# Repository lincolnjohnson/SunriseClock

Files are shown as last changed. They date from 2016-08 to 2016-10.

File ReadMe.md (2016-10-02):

# Arduino SunriseClock v3.2 #
https://github.com/lincolnjohnson/SunriseClock
ReadMe file  
Lincoln Johnson August 2016



---

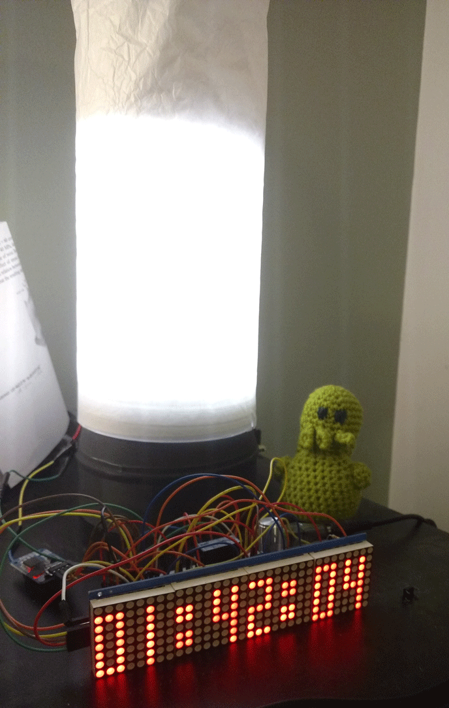
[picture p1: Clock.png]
Crochet Cthulu for scale


## Introduction ##

An LED sunrise clock using an Arduino Pro Micro, 5M 5630 LED strip (300 LEDs/strip), HT1632C 8X32 LED module, DS3231 RTC Module, and rotary encoder with built-in switch.

I've tried a few of the commercially available sunrise clocks, and none of them seem to go bright enough to really help me wake up. So I went with "bigger is better," and maybe a little too far. The LED strip pulls ~72W of power at full brightness, and at 8.5% is sufficient as a standalone light to read or work by.

Should provide ~10,000 lumens at full brightness. Compare that to off-the-shelf sunrise clocks, which generally provide ~300-800 lumens... It's bright enough to hurt my eyes from across the room, and definitely gets me out of bed. I didn't build in functionality to limit the brightness or change the sunrise length, but these would be reasonably trivial to implement if desired.

The clock can be set to natually shift along with the natural sunrise if desired so that you wake up with the real sunrise during the summer months when it shifts earlier.

I've included a schematic and Eagle files for PCB printing. The PCB is designed to be split into two boards, one for the arduino, one for the rotary encoder and switch to be mounted near the top of the case I've designed. Case plans are in the Drawings folder.

Functionality included:

- 16-bit PWM control of LED lamp brightness
- Sunrise brightness uses an exponential function to ramp up brightness in a way that appears linear to the human eye
- User defined Sunrise (alarm) start time, ramps up over 30 minutes
- Choose to have sunrise follow the natural sunrise time or not (with the latest time being the above defined time)
- Automatic dimming after two hours at full brightness
- User-adjustable brightness of light when outside of sunrise period
- Set RTC clock using rotary encoder
- Automatic RTC adjustment for DST
- TODO: ADD WEEKEND AUTOMATIC ADJUSTMENT FOR EXTRA SLEEP TIME

Essentially, once initial program is loaded onto clock it never needs to be re-connected unless you want to update the baseline functionality. You can do everything you should need to do through the various menus.

I made some minor adjustments to a couple of the included libraries or used non-standard versions, so they're included in this repository as well so as to make your life easier if you want to compile/build this. Everything in the includes folder is not my own original work. The other included files listed such as EEPROM and Wire are standard arduino versions.

There are dual signal wires to the MOSFET controlling the LEDs because it seemed that one signal wire wasn't allowing the system to open fully when using a transistor. Not sure why, but doubling up appears to have fixed it - at full duty cycle it's just as bright as a direct connection to power, especially with the first MOSFET switching the source voltage to drive the second one. Now that I've switched to using a MOSFET, one is fine but two signals doesn't hurt so I left it. If you need the extra pin for something else you can always remove one of 9/10 and update the code appropriately.

The Pro Micro tends to be cranky with the Arduino IDE sometimes, especially if you are trying to load code to it for the first time, or switching between sketches. I find that jumpering the RST and GND pins, pressing upload on the IDE, and then disconnecting the jumper as soon as the IDE finishes compiling and outputs the size of the files used fixes this problem. Subsequent uploads with the same sketch should work fine. Not sure if this is a problem related to my use of cheap ebay clones.

I strongly suggest you use a high-quality power supply, as when cheap ebay ones start to die they tend to send out significant voltage spikes that fry things... such as your Arduino.

"Arduino SunriseClock v3.2" by Lincoln Johnson is licensed under CC BY-SA 4.0.
Included libraries are licensed under the licenses provided by their respective creators.

## Usage notes ##

- Run InitialSetup.ino on your Arduino board to initialize EEPROM values and set the time on your RTC [alternatively, these can all be set through the configuration menu]
- Update latitude and longitude values for your location in SunriseClock.ino
- Run SunriseClock.ino on your Arduino board

Pushbutton used to:

- Cancel sunrise if you wake up before it completes
- Toggle clock and light on or off when outside sunrise period and not in configuration menu
- Go back one level in configuration menu, or exit config if on top level

Rotary encoder used to:

- Cycle between configuration menu options or option settings
- Pushbutton used to enter config menu or select menu option displayed

## Electronics BOM ##

- 1x Arduino Pro Micro (Nano also tested and works for base functionality, changes would need to be made to schematic)
- 1x 80W+ power supply (PMT-12V100W1AA)
- 1x 5m 5630 LED strip
- 1x RTC Clock (ebay DS3231 clock module board)
- 1x 8x32 LED display board with HT1632C controller
- 1x 12v->5V DC converter (BP5293-50)
- 1x Pushbutton switch (1825910-6)
- 1x Rotary encoder with pushbutton switch (EN12-HS22AF20)
- 2x 0.1uF capacitor (K104K10X7RF5UH5)
- 2x n-channel mosfet (FQU13N06L)
- 2x 100ohm resistors
- 2x 100kohm resistors
- 2x 12 pin female headers to enable easy replacement of arduino in case of failure (PPTC121LFBN-RC)
- 3x 6 pin headers to connect 3208 matrix and switches board (1x 801-87-006-20-001101 right angle for 3208 & 2x 310-87-106-41-001101 for switches)
- 1x 5 pin header to connect RTC (310-87-105-41-001101)
- 1x 2 pin header to connect LED strip (310-87-102-41-001101)
- 1x screw terminal header for power connection to power supply (1935161)
- Various hookup/connection wires
- Breadboard if no PCB

## Materials used for physical build ##

- 1x 5" to 4" ducting reducer, spray painted matte black
- 1x 4" ducting connector
- 1x 4" ducting cap
- 1x 5" DIA 9" height acrylic canister with white tissue paper as shade
- 1x AC power entry connector (701W-X2/02 or similar)
- 1x Aluminum knob for rotary encoder (Ebay)
- 1x Pushbutton cap for switch (TAGCHR)
- 4.5 ft of 6" wide hardwood for case

## Main Board Schematic ##

This is the main board without the rotary encoder and button on it. If you want it on one board, remove the TOSWITCHES headers and connect them as required.

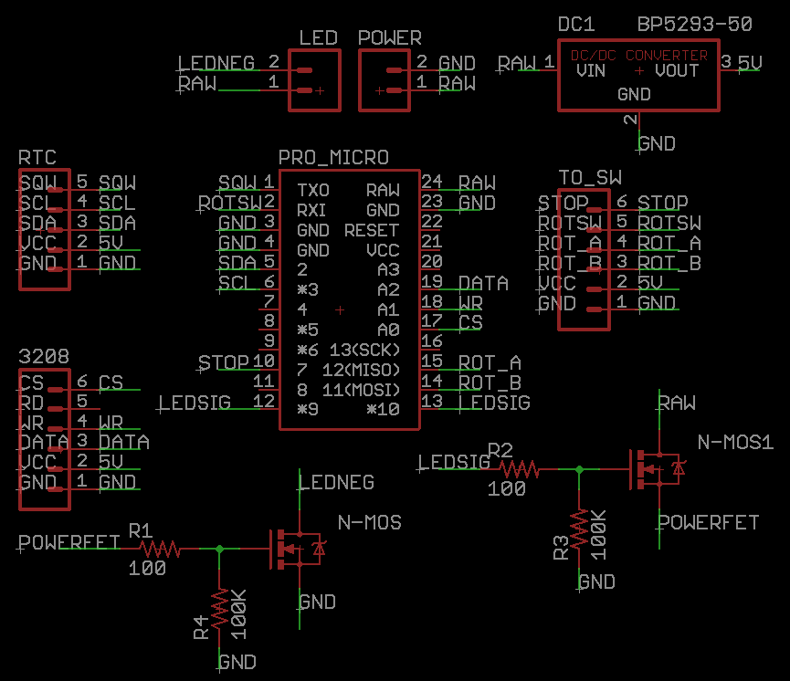
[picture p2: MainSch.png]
Main board schematic


## Eagle Main Board PCB ##

I haven't tested this board yet as it hasn't shown up from the fab. It's probably wrong/may cause a black hole to form and destroy the planet. Use at your own risk. Board size: 1.5464 sqin.

This will need additional physical wires soldered on the LED power ciruit to handle the ~72W power drain if you use the set trace length.

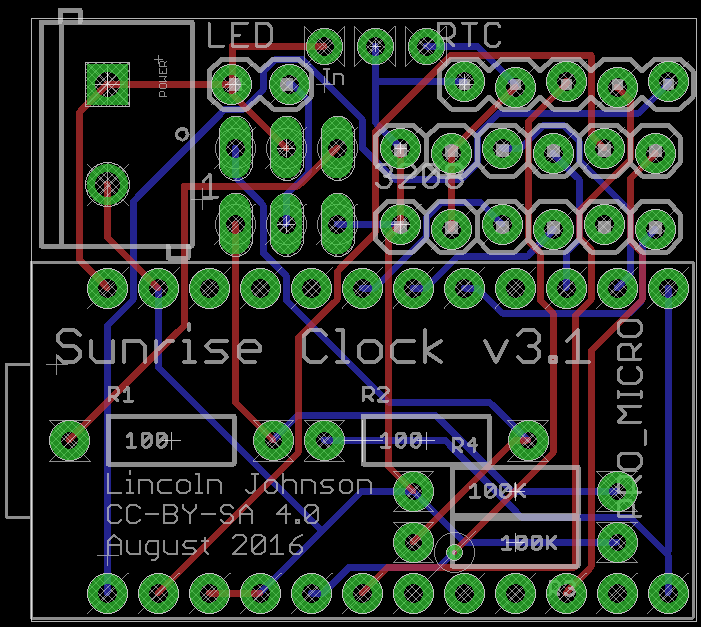
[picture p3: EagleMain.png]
Main eagle PCB


## Switches Board Schematic ##

This is the board with the rotary encoder and button on it. If you want it on one board, remove the TOSWITCHES headers and connect them as required.

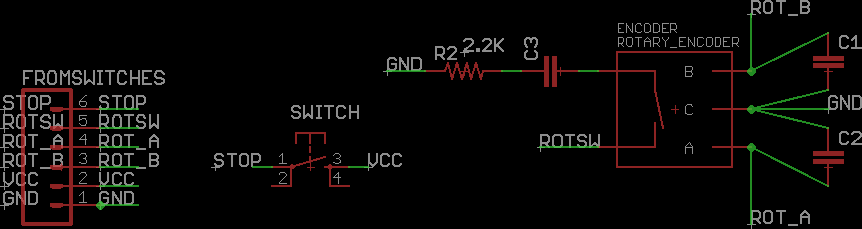
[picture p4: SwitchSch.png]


## Eagle Switches Board PCB ##

I haven't tested this board yet as it hasn't shown up from the fab. It's probably wrong/may cause a black hole to form and destroy the planet. Use at your own risk. Board size: 1.1135 sqin.

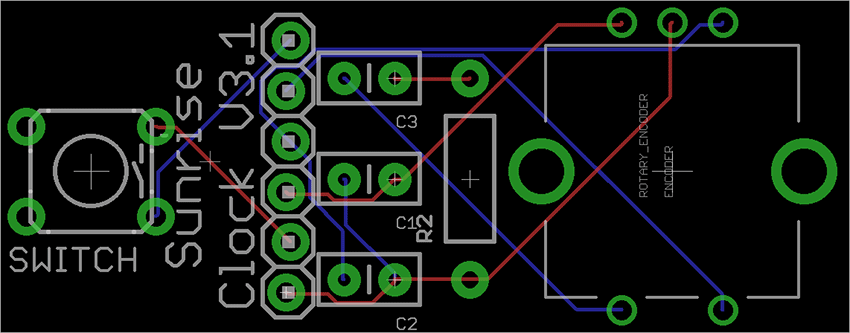
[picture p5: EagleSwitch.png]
Main eagle PCB


## Case Design ##

Complete drawings follow below. Sides not shown as they are solid. PDF with full instructions for construction in Drawings folder.

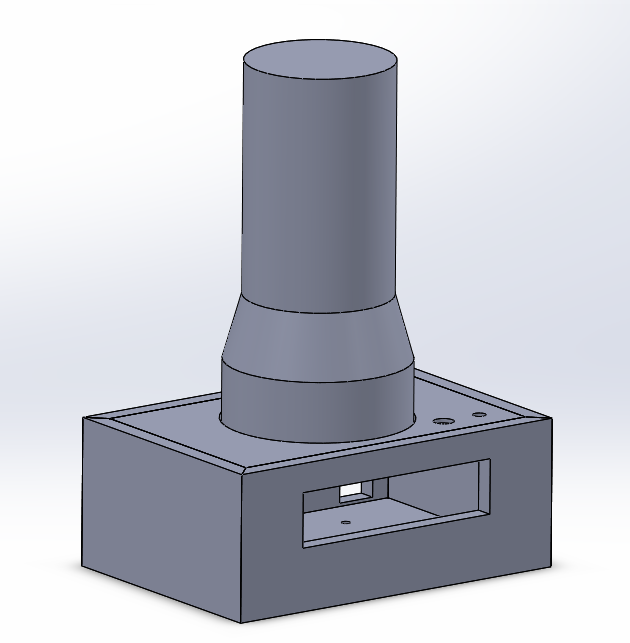
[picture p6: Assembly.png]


###Completed case

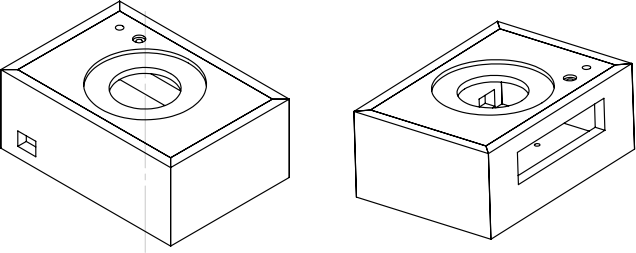
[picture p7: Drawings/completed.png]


###Base drawings

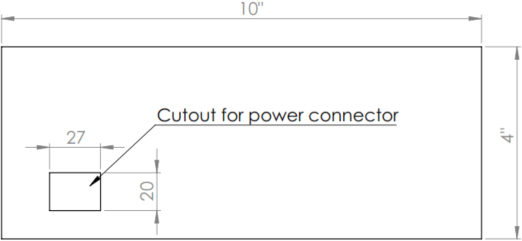
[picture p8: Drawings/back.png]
Base drawings


###Front drawings

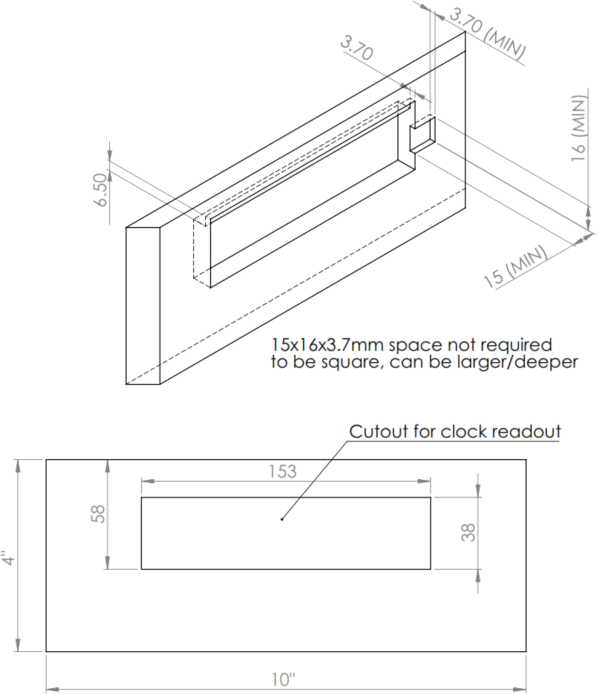
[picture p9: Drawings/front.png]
Front drawings


###Top drawings

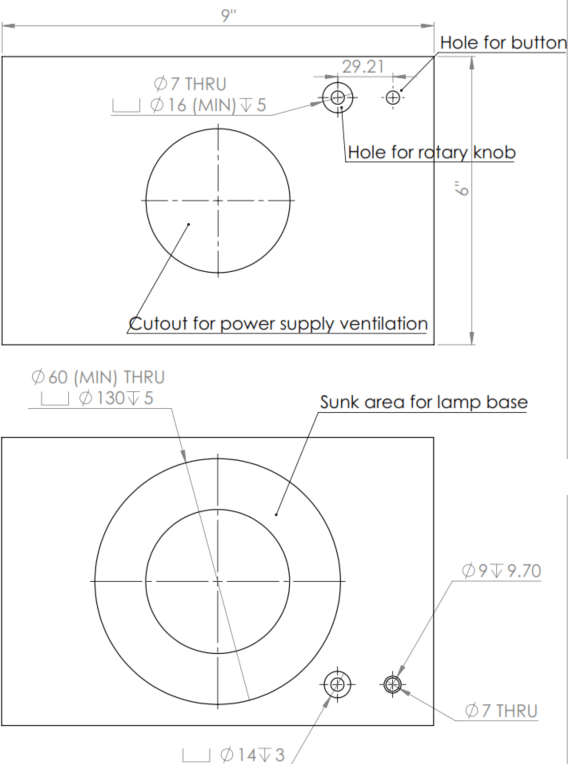
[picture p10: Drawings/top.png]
Top drawings


###Back drawings

Back drawings

## SunriseClock Functions ##

###ISR(PCINT0_vect)
#####Description
Reads the inputs from the rotary encoder gray code to determine if an increment or decrement is desired

###void stop()
#####Description
Called by interrupt, reads the inputs from pushbutton with software debouncing
#####Syntax
`stop();`
#####Parameters
None.
#####Returns
Nothing.

###void toggleLamp(boolean on)
#####Description
Toggles lamp on or off
#####Syntax
`toggleLamp(0);`
#####Parameters
*(boolean)* on - 0 or false is off, 1 or true is on
#####Returns
Nothing.

###void timeUpdate()
#####Description
Called by interrupt generated by 1HZ square wave from RTC - calls showClock() if lamp is on
#####Syntax
`timeUpdate();`
#####Parameters
None.
#####Returns
Nothing.

###void ShowClock()
#####Description
Updates clock display based on current time
#####Syntax
`ShowClock();`
#####Parameters
None.
#####Returns
Nothing.

###bool IsDST()
#####Description
Checks if current time is in DST or not
#####Syntax
`IsDST();`
#####Parameters
None.
#####Returns
0 if currently not in DST, 1 if in DST

###void CheckDST()
#####Description
Checks if currently in DST, updates relevant EEPROM values if there has been a change, updates time on RTC
#####Syntax
`CheckDST();`
#####Parameters
None.
#####Returns
Nothing.

###void setBrightness(unsigned int set)
#####Description
Updates clock brightness
#####Syntax
`setBrightness(60000);`
#####Parameters
*(unsigned int)* set - 65536 is off, 0 is full brightness
#####Returns
Nothing.

###unsigned int readBright()
#####Description
Reads current brightness setting
#####Syntax
`readBright();`
#####Parameters
None.
#####Returns
Current brightness level *(unsigned int)*

###void getSunrise()
#####Description
Calculates sunrise time for next day, updates RTC alarm as necessary
#####Syntax
`getSunrise();`
#####Parameters
None.
#####Returns
Nothing.

###void toggleBlink(boolean blinky)
#####Description
Toggles 250ms blink cycle on LED screen
#####Syntax
`toggleBlink(true);`
#####Parameters
*(boolean)* blinky
#####Returns
Nothing.

###void ClockMenu(String text)
#####Description
Updates LED screen (for when in configuration menu)
#####Syntax
`ClockMenu("Set Clk");`
#####Parameters
*(String)* text
#####Returns
Nothing.

###void knobPress()
#####Description
Controls functionality of rotary encoder switch. Enters menu if currently in clock mode, otherwise selects current menu item shown on LED. Includes software debounce.
#####Syntax
`knobPress();`
#####Parameters
None.
#####Returns
Nothing.

###void KnobSelect()
#####Description
Updates LCD screen for menu navigation
#####Syntax
`KnobSelect();`
#####Parameters
None.
#####Returns
Nothing.

###void KnobUpdate()
#####Description
Called by encoder ISR. Controls update of all config variables, EEPROM updates as necessary.
#####Syntax
`KnobUpdate();`
#####Parameters
None.
#####Returns
Nothing

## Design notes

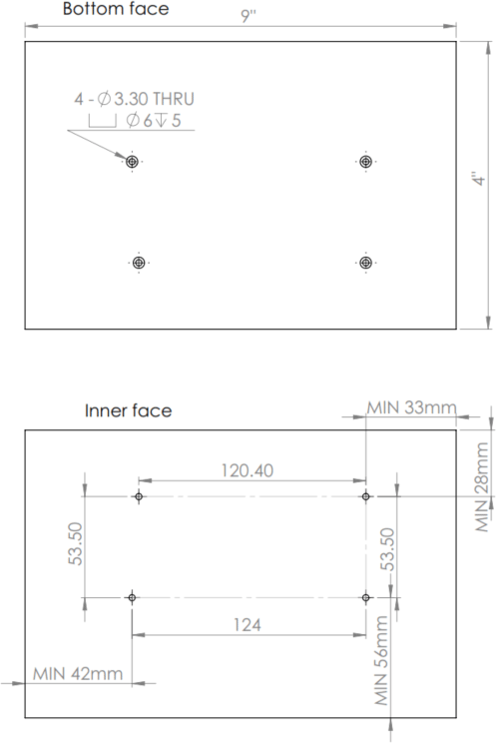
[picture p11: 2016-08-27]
Drawings/base.png

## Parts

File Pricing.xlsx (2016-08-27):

DIGIKEY | Unit cost | Number | Total
TAGCHR | $0.74 | 1 | $0.74
701W-X2/02 | $1.11 | 1 | $1.11
1935161 | $0.53 | 1 | $0.53
310-87-102-41-001101 | $0.30 | 1 | $0.30
310-87-105-41-001101 | $0.51 | 1 | $0.51
801-87-006-20-001101 | $1.12 | 1 | $1.12
310-87-106-41-001101 | $0.63 | 2 | $1.26
FQU13N06L | $1.02 | 1 | $1.02
K104K10X7RF5UH5 | $0.26 | 2 | $0.52
EN12-HS22AF20 | $1.56 | 1 | $1.56
1825910-6 | $0.10 | 1 | $0.10
PMT-12V100W1AA | $32.00 | 1 | $32.00
OSH Park
PCB | $5.76 | 3 | $17.29
Ebay
LED Module (http://www.ebay.com/itm/5M-3528-5050-5630-7020-SMD-LED-Flexible-Waterproof-Strip-String-Light-12V-/351547096821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) | $7.28 | 1 | $7.28
RTC (http://www.ebay.com/itm/Arduino-DS3231-AT24C32-IIC-Module-Precision-RTC-Real-Time-Clock-Quare-Memory-/262123918224) | $0.99 | 1 | $0.99
Pro Micro (http://www.ebay.com/itm/1PCS-Leonardo-Pro-Micro-ATmega32U4-Arduino-IDE-1-0-3-Bootloader-replace-Pro-Mini-/221988214316) | $5.37 | 1 | $5.37
LED matrix (http://www.ebay.com/itm/New-Lattice-Breakout-LED-Module-8X32-Red-Dot-Matrix-Screen-HT1632C-/321866908598) | $14.12 | 1 | $14.12

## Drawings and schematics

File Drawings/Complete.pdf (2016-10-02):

E

F

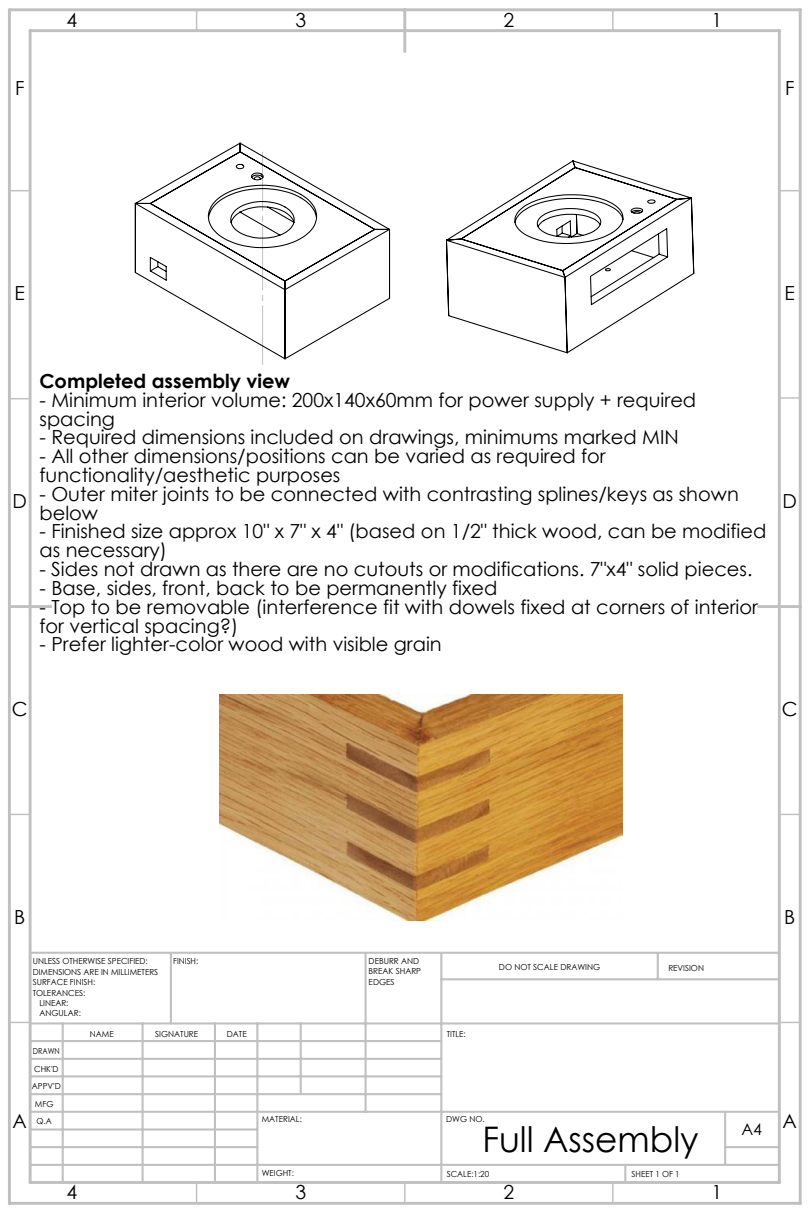
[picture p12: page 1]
FINISH:; DEBURR AND; BREAK SHARP EDGES; DO NOT SCALE DRAWING; REVISION; SCALE:1:20; SHEET 1 OF 1; WEIGHT:

Completed assembly view
- Minimum interior volume: 200x140x60mm for power supply + required
spacing
- Required dimensions included on drawings, minimums marked MIN
- All other dimensions/positions can be varied as required for
functionality/aesthetic purposes
- Outer miter joints to be connected with contrasting splines/keys as shown
below
- Finished size approx 10" x 7" x 4" (based on 1/2" thick wood, can be modified
as necessary)
- Sides not drawn as there are no cutouts or modifications. 7"x4" solid pieces.
- Base, sides, front, back to be permanently fixed
- Top to be removable (interference fit with dowels fixed at corners of interior
for vertical spacing?)
- Prefer lighter-color wood with visible grain

UNLESS OTHERWISE SPECIFIED:
DIMENSIONS ARE IN MILLIMETERS
SURFACE FINISH:
TOLERANCES:
LINEAR:
ANGULAR:

NAME | SIGNATURE | DATE | | | | TITLE:

DRAWN
CHK'D
APPV'D
MFG
Q.A | | | | MATERIAL: | DWG NO. Full Assembly | A4

# 4 - 3.30 THRU

6 5

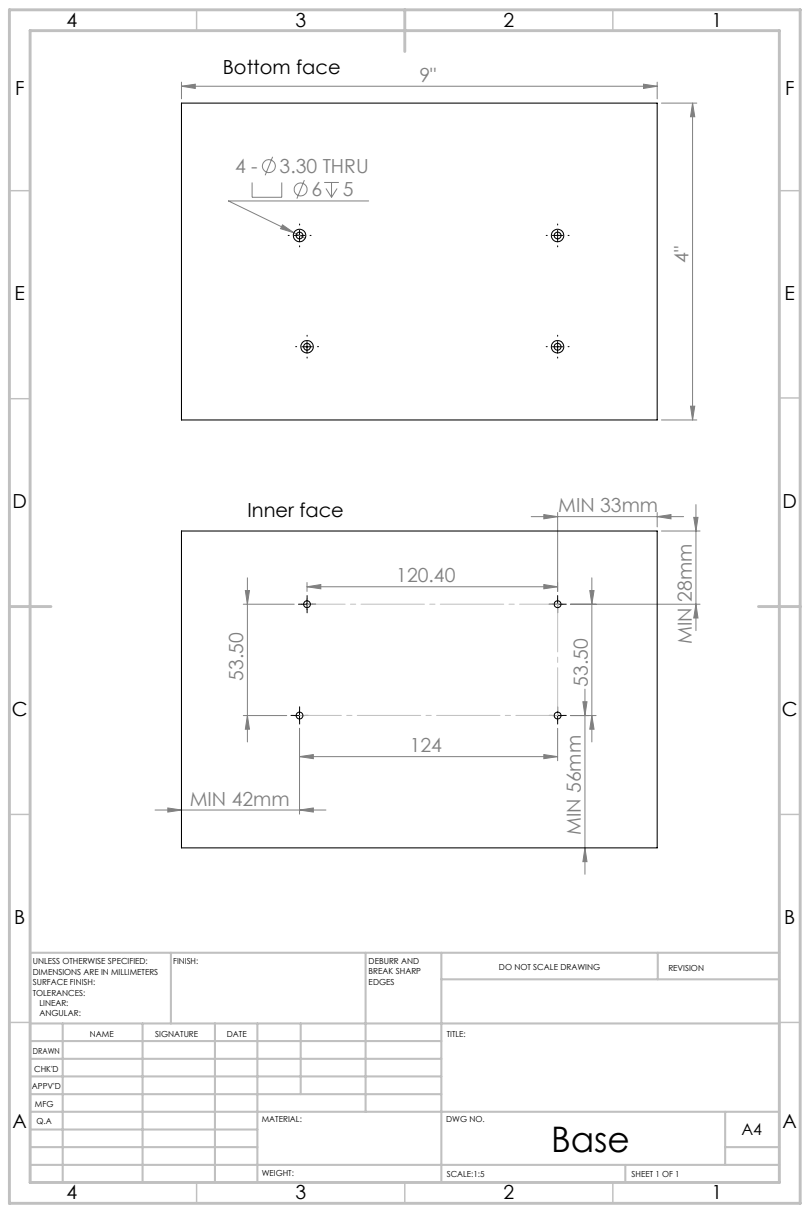
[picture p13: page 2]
Bottom face 53.50; MIN 56mm; MIN 28mm; MIN 33mm; MIN 42mm; Inner face; FINISH:; DEBURR AND; BREAK SHARP EDGES; DO NOT SCALE DRAWING; REVISION

UNLESS OTHERWISE SPECIFIED:
DIMENSIONS ARE IN MILLIMETERS
SURFACE FINISH:
TOLERANCES:
LINEAR:
ANGULAR:

NAME | SIGNATURE | DATE | | | TITLE:

DRAWN
CHK'D
APPV'D
MFG

Base

SCALE:1:5 | SHEET 1 OF 1

# 7 THRU 16 (MIN) 5

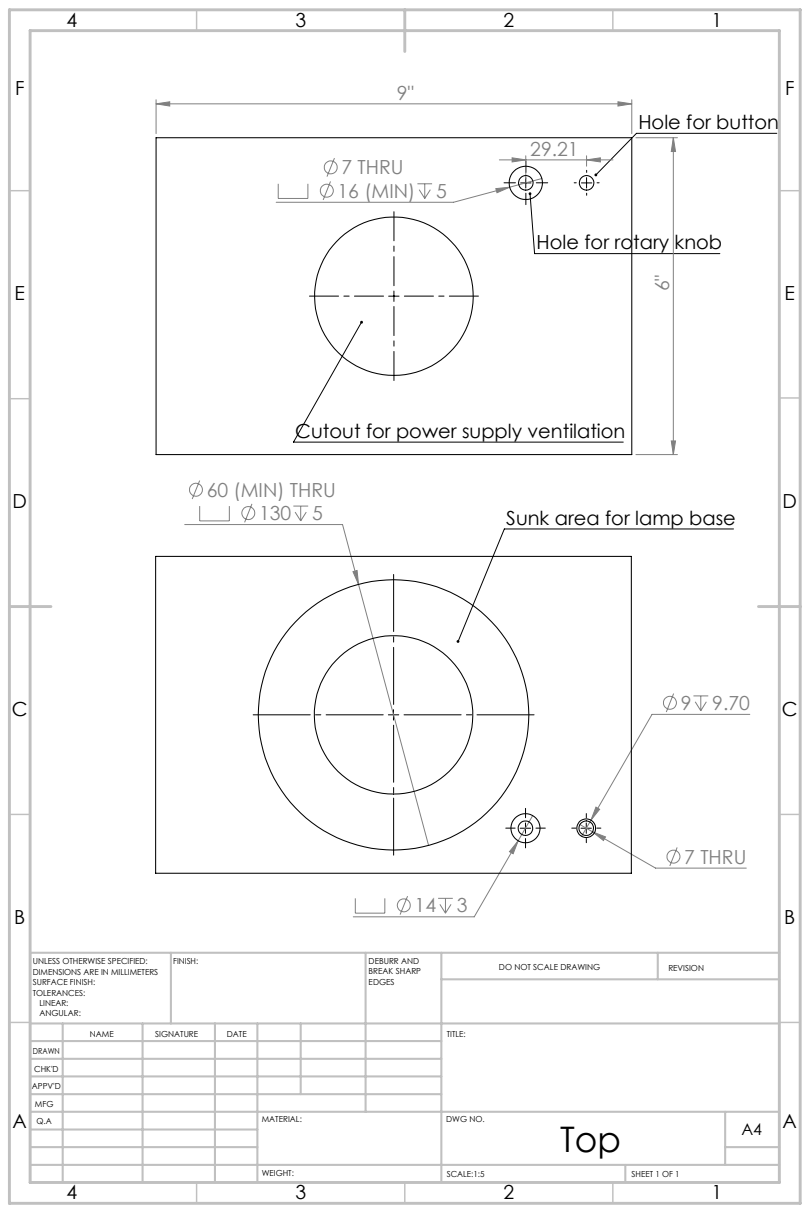
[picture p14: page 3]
60 (MIN) THRU 130 5; 7 THRU; FINISH:; DEBURR AND; BREAK SHARP EDGES; DO NOT SCALE DRAWING; REVISION

Hole for button

Hole for rotary knob

Cutout for power supply ventilation

Sunk area for lamp base

UNLESS OTHERWISE SPECIFIED:
DIMENSIONS ARE IN MILLIMETERS
SURFACE FINISH:
TOLERANCES:
LINEAR:
ANGULAR:

NAME | SIGNATURE | DATE | | TITLE:

DRAWN
CHK'D
APPV'D
MFG

Top

E

F

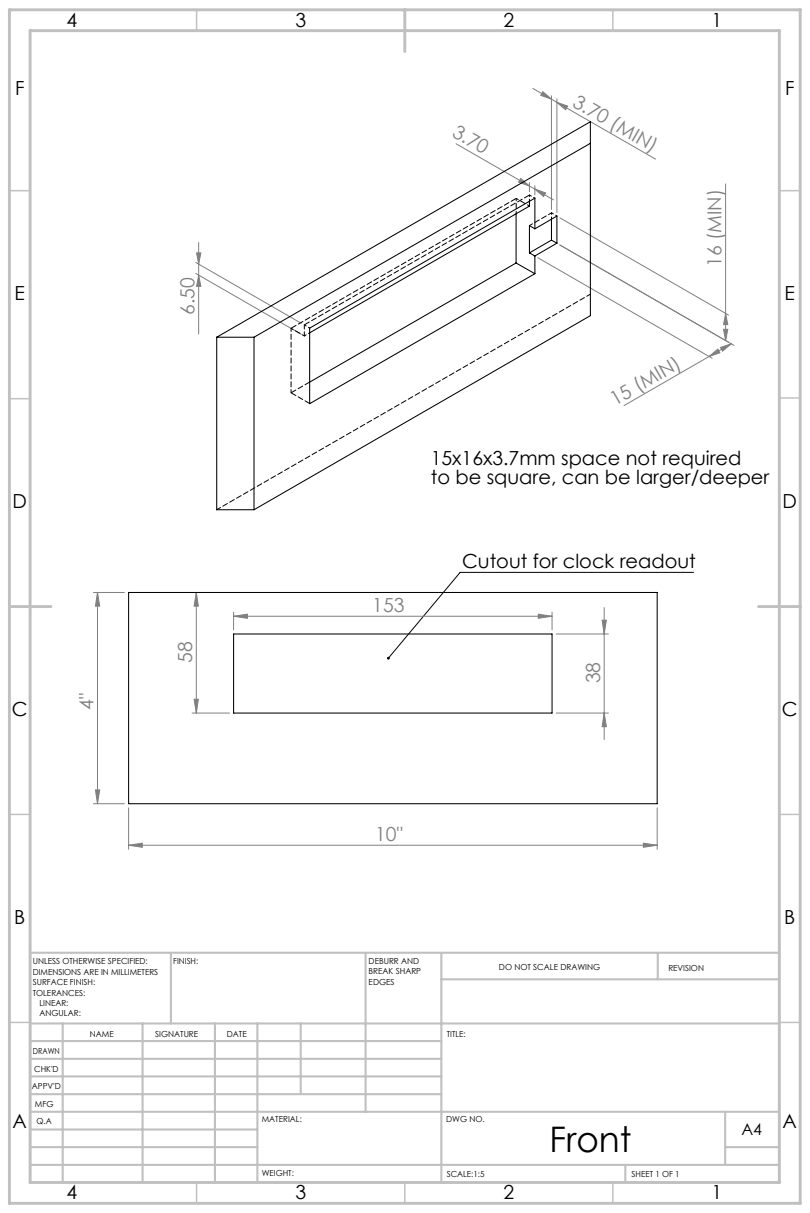
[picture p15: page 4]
3.70 (MIN); 15 (MIN); 16 (MIN); FINISH:; DEBURR AND; BREAK SHARP EDGES; DO NOT SCALE DRAWING; REVISION

15x16x3.7mm space not required
to be square, can be larger/deeper

Cutout for clock readout

UNLESS OTHERWISE SPECIFIED:
DIMENSIONS ARE IN MILLIMETERS
SURFACE FINISH:
TOLERANCES:
LINEAR:
ANGULAR:

NAME | SIGNATURE | DATE | | TITLE:

DRAWN
CHK'D
APPV'D
MFG

Front

10"

E

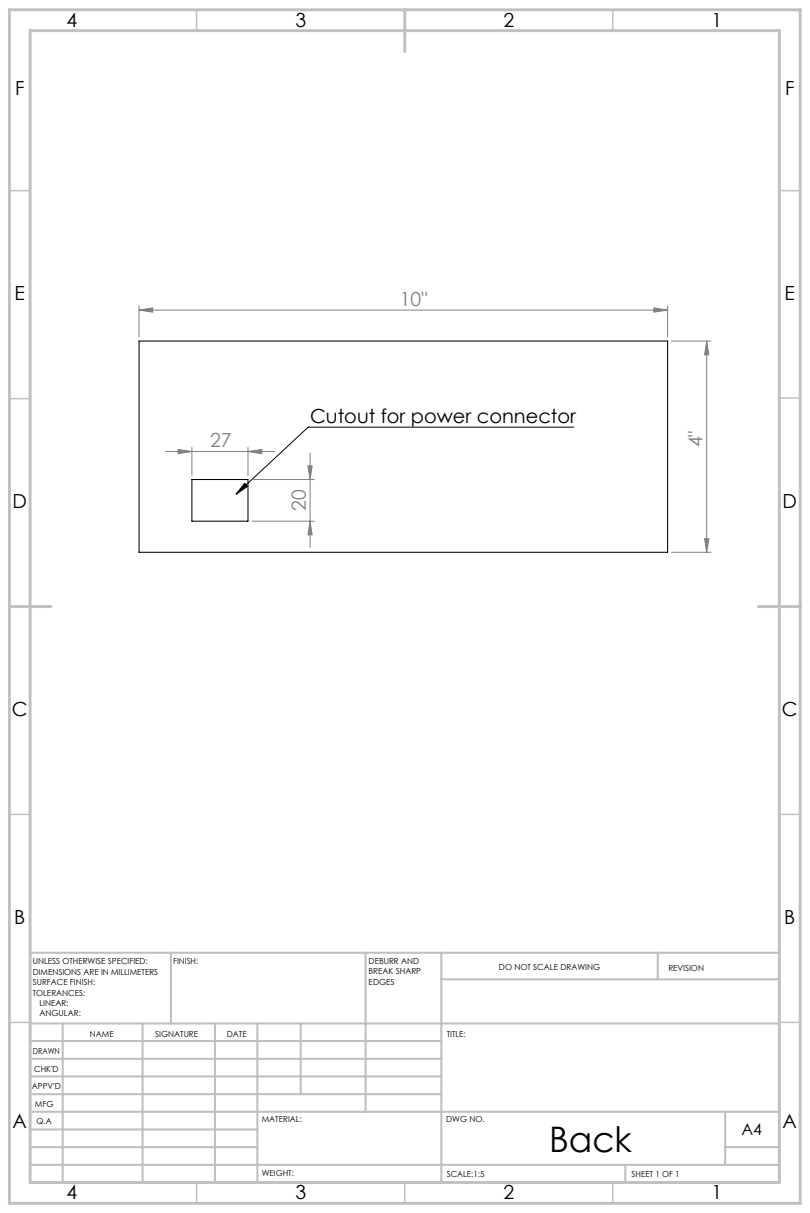
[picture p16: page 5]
FINISH:; DEBURR AND; BREAK SHARP EDGES; DO NOT SCALE DRAWING; REVISION

Cutout for power connector

UNLESS OTHERWISE SPECIFIED:
DIMENSIONS ARE IN MILLIMETERS
SURFACE FINISH:
TOLERANCES:
LINEAR:
ANGULAR:

NAME | SIGNATURE | DATE | | TITLE:

DRAWN
CHK'D
APPV'D
MFG

Back

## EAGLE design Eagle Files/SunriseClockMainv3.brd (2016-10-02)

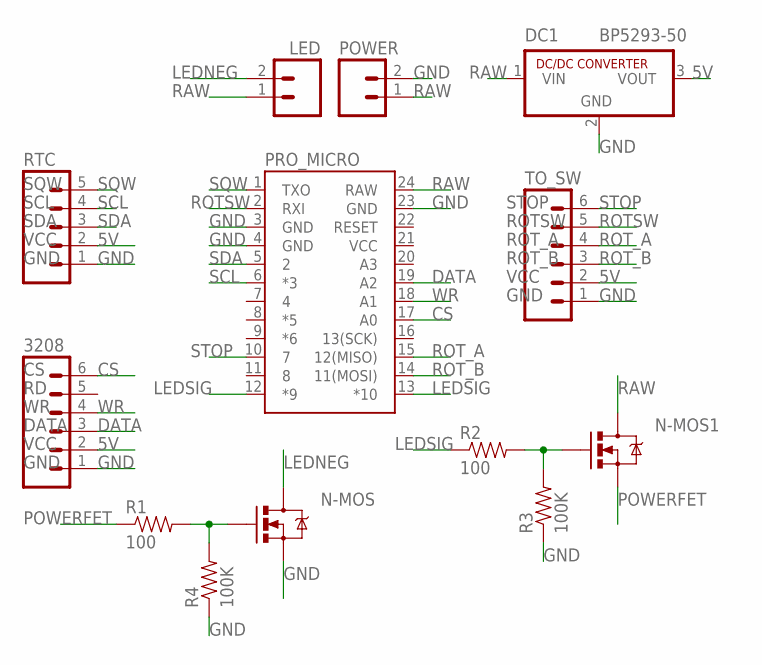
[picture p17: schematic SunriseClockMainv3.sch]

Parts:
3208: M06LOCK; 1X06_LOCK
DC1: BP5293-50; SIP3
LED: M02LOCK; 1X02_LOCK
N-MOS, N-MOS1: MOSFET-NCHANNELFQP30N06L; TO220V
POWER: M025MM; SCREWTERMINAL-5MM-2
PRO_MICRO: ARDUINO_PRO_MICRO
R1, R2: 100; AXIAL-0.4
R3, R4: 100K; AXIAL-0.4
RTC: M05LOCK; 1X05_LOCK
TO_SW: M06LOCK; 1X06_LOCK

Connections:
5V: 3208.2, DC1.3 (VOUT), RTC.2, TO_SW.2
CS: 3208.6, PRO_MICRO.17 (A0)
DATA: 3208.3, PRO_MICRO.19 (A2)
GND: 3208.1, DC1.2 (GND), N-MOS.3 (S), POWER.2, PRO_MICRO.3 (GND), PRO_MICRO.4 (GND), PRO_MICRO.23 (GND), R3.P$1 (1), R4.P$1 (1), RTC.1, TO_SW.1
LEDNEG: LED.2, N-MOS.2 (D)
LEDSIG: PRO_MICRO.12 (*9), PRO_MICRO.13 (*10), R2.P$1 (1)
unnamed: N-MOS.1 (G), R1.P$2 (2), R4.P$2 (2)
unnamed: N-MOS1.1 (G), R2.P$2 (2), R3.P$2 (2)
POWERFET: N-MOS1.3 (S), R1.P$1 (1)
RAW: DC1.1 (VIN), LED.1, N-MOS1.2 (D), POWER.1, PRO_MICRO.24 (RAW)
ROTSW: PRO_MICRO.2 (RXI), TO_SW.5
ROT_A: PRO_MICRO.15 (12(MISO)), TO_SW.4
ROT_B: PRO_MICRO.14 (11(MOSI)), TO_SW.3
SCL: PRO_MICRO.6 (*3), RTC.4
SDA: PRO_MICRO.5 (2), RTC.3
SQW: PRO_MICRO.1 (TXO), RTC.5
STOP: PRO_MICRO.10 (7), TO_SW.6
WR: 3208.4, PRO_MICRO.18 (A1)

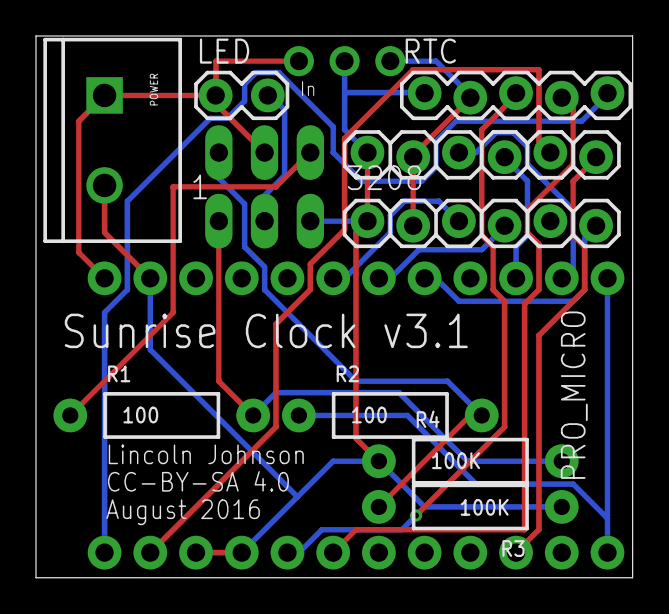
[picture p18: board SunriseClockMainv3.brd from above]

Board: 2 copper layers, 33.1 x 30.1 mm, 13 parts (0 on the bottom side), 18 nets.

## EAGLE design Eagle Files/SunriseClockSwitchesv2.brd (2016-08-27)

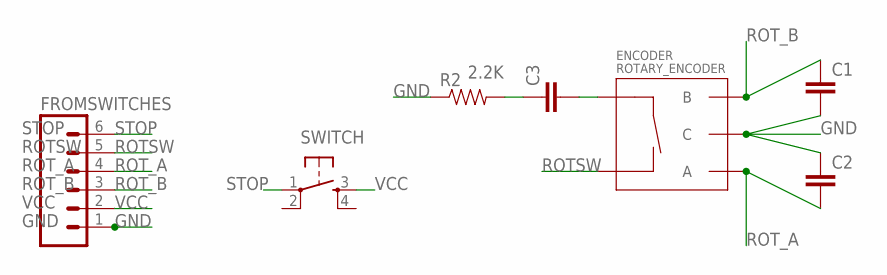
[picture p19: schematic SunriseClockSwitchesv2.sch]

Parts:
C1, C2, C3: CAPEZ; CAP-PTH-SMALLEZ
ENCODER: ROTARY_ENCODER; ROTARY_ENC_PLAIN
FROMSWITCHES: M06LOCK; 1X06_LOCK
R2: RESISTORPTH-1/4W; AXIAL-0.4
SWITCH: TAC_SWITCHPTH; TACTILE-PTH

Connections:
GND: C1.2, C2.1, ENCODER.C, FROMSWITCHES.1, R2.P$1 (1)
unnamed: C3.1, R2.P$2 (2)
unnamed: C3.2, ENCODER.SW+
ROTSW: ENCODER.SW-, FROMSWITCHES.5
ROT_A: C2.2, ENCODER.A, FROMSWITCHES.4
ROT_B: C1.1, ENCODER.B, FROMSWITCHES.3
STOP: FROMSWITCHES.6, SWITCH.1
VCC: FROMSWITCHES.2, SWITCH.3

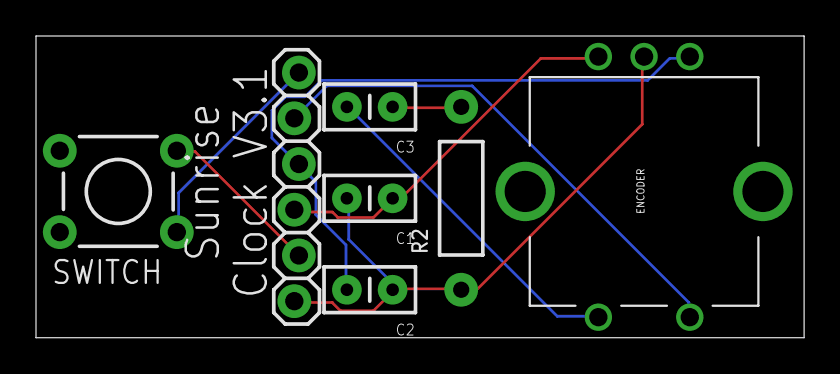
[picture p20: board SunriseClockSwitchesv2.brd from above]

Board: 2 copper layers, 42.7 x 16.8 mm, 7 parts (0 on the bottom side), 8 nets.

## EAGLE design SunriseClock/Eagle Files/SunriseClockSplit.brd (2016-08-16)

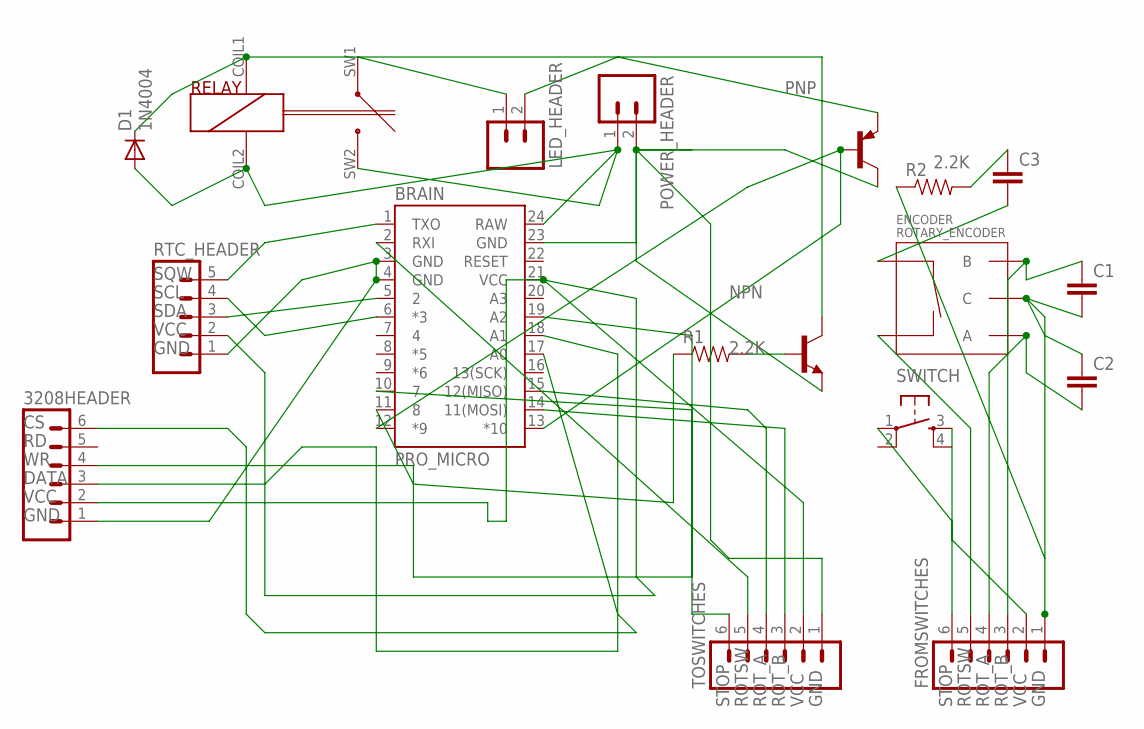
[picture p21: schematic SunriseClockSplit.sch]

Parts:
3208HEADER: M06LOCK; 1X06_LOCK
BRAIN: PRO_MICRO; ARDUINO_PRO_MICRO
C1, C2, C3: CAPEZ; CAP-PTH-SMALLEZ
D1: 1N4004; DO41-10
ENCODER: ROTARY_ENCODER; ROTARY_ENC_PLAIN
FROMSWITCHES: M06LOCK; 1X06_LOCK
LED_HEADER: M02LOCK; 1X02_LOCK
NPN: -NPN-TO126V; TO126V
PNP: -PNP-TO126V; TO126V
POWER_HEADER: M025MM; SCREWTERMINAL-5MM-2
R1, R2: RESISTORPTH-1/4W; AXIAL-0.4
RELAY: RELAY; HALLER_RELAIS_2PIN
RTC_HEADER: M05LOCK; 1X05_LOCK
SWITCH: TAC_SWITCHPTH; TACTILE-PTH
TOSWITCHES: M06LOCK; 1X06_LOCK

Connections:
unnamed: BRAIN.24 (RAW), D1.A, POWER_HEADER.1, RELAY.COIL2, RELAY.SW2
unnamed: LED_HEADER.1, RELAY.SW1
unnamed: LED_HEADER.2, PNP.1 (E)
unnamed: FROMSWITCHES.6, SWITCH.1
unnamed: BRAIN.12 (*9), BRAIN.13 (*10), PNP.3 (B)
unnamed: BRAIN.11 (8), R1.P$1 (1)
unnamed: NPN.3 (B), R1.P$2 (2)
unnamed: C1.1, ENCODER.B, FROMSWITCHES.3
unnamed: BRAIN.23 (GND), NPN.1 (E), PNP.2 (C), POWER_HEADER.2, TOSWITCHES.1
unnamed: C2.2, ENCODER.A, FROMSWITCHES.4
unnamed: C3.1, R2.P$2 (2)
unnamed: C3.2, ENCODER.SW+
unnamed: BRAIN.2 (RXI), TOSWITCHES.5
unnamed: BRAIN.10 (7), TOSWITCHES.6
unnamed: FROMSWITCHES.2, SWITCH.3
unnamed: BRAIN.1 (TXO), RTC_HEADER.5
unnamed: C1.2, C2.1, ENCODER.C, FROMSWITCHES.1, R2.P$1 (1)
unnamed: 3208HEADER.2, BRAIN.21 (VCC), RTC_HEADER.2, TOSWITCHES.2
unnamed: BRAIN.6 (*3), RTC_HEADER.4
unnamed: BRAIN.5 (2), RTC_HEADER.3
unnamed: ENCODER.SW-, FROMSWITCHES.5
unnamed: 3208HEADER.1, BRAIN.3 (GND), BRAIN.4 (GND), RTC_HEADER.1
unnamed: 3208HEADER.6, BRAIN.17 (A0)
unnamed: 3208HEADER.4, BRAIN.18 (A1)
unnamed: 3208HEADER.3, BRAIN.19 (A2)
unnamed: BRAIN.15 (12(MISO)), TOSWITCHES.4
unnamed: BRAIN.14 (11(MOSI)), TOSWITCHES.3
unnamed: D1.C, NPN.2 (C), RELAY.COIL1

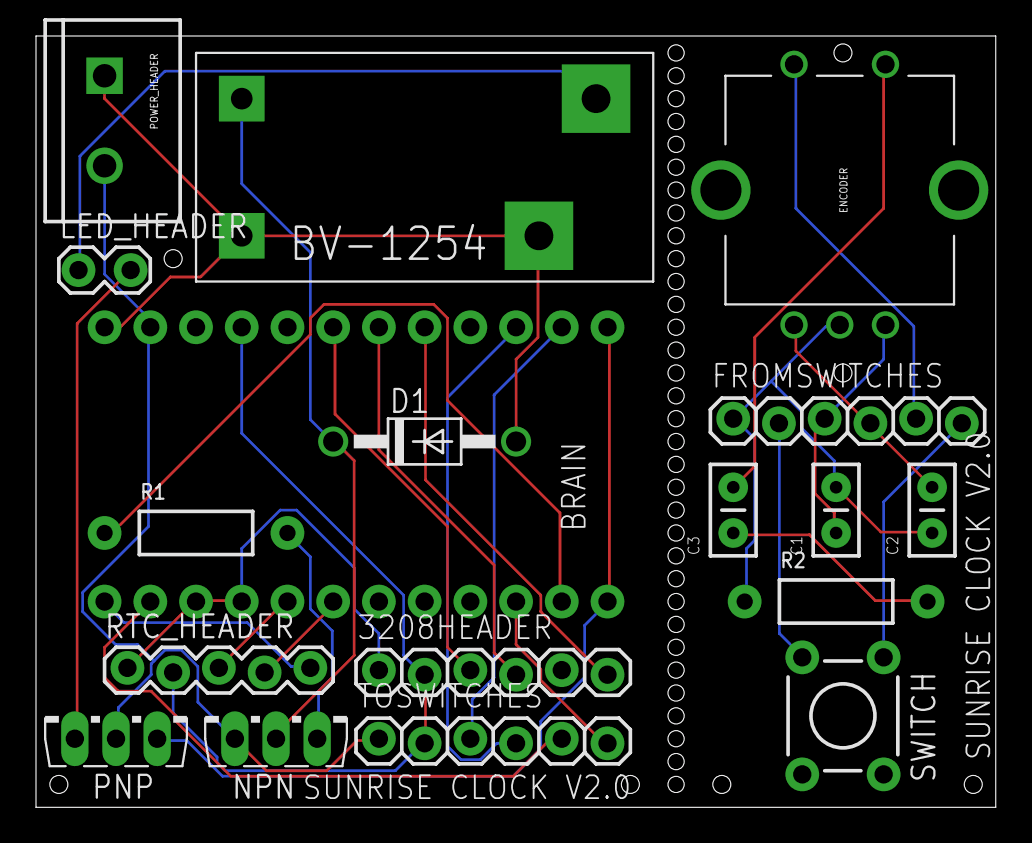
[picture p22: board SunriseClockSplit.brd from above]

Board: 2 copper layers, 53.3 x 42.9 mm, 18 parts (0 on the bottom side), 28 nets.

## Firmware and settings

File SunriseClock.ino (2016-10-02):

//https://www.circuitsathome.com/mcu/reading-rotary-encoder-on-arduino
//https://www.circuitsathome.com/mcu/rotary-encoder-interrupt-service-routine-for-avr-micros

#include <EEPROM.h>           //https://www.arduino.cc/en/Reference/EEPROM
#include <TimeLord.h>         //https://github.com/probonopd/TimeLord
#include <HT1632.h>           //https://github.com/gauravmm/HT1632-for-Arduino
#include <font_7X5.h>         //https://github.com/gauravmm/HT1632-for-Arduino
#include <font_5x4.h>         //https://github.com/gauravmm/HT1632-for-Arduino
#include <DS3232RTC.h>        //http://github.com/JChristensen/DS3232RTC
#include <Time.h>             //https://github.com/PaulStoffregen/Time
#include <TimeLib.h>          //https://github.com/PaulStoffregen/Time
#include <Wire.h>             //http://arduino.cc/en/Reference/Wire

const boolean debugbit = false;

const byte pulsePin = 9;
const byte pulsePin2 = 10;
const byte stopPin = 7;

const byte SQWPin = 1;

//LED Screen pins
const byte pinDATA = 19;
const byte pinWR = 20;
const byte pinCS1 = 18;

//EEPROM Vars
const byte DST = 100;
const byte BrightStor = 101;
const byte MaxHour = 102;
const byte MaxMinute = 103;
const byte EESunFollow = 104;
const byte SunOn = 105;

unsigned long targetMillis = 0;
const unsigned long interval = 1757;

long duty = 0;
const int steps = 1024;

//alarm stuff
// SET EARLIEST SUNRISE LIMITS - 1 hour before latest?
volatile byte latestHour;
volatile byte latestMin;
volatile byte alarmHour;
volatile byte alarmMinute;
volatile boolean alarmed = false;
volatile boolean tripped = false;
time_t alarmStart;

//timelord stuff
const float latitude = 49;
const float longitude = -119;
volatile boolean gotSunrise = false;

//brightness var
volatile unsigned int brightLevel;

//rotary encoder
#define ENC_WR  PORTB //encoder port write  
#define ENC_RD  PINB  //encoder port read
#define ENC_A 14 // Bent cap pin to 14
#define ENC_B 16
const byte switchPin = 0; // for rotary switch
volatile int encVal = 0;
volatile uint8_t old_AB = 0;
volatile const int8_t enc_states [] = {0, -1, 1, 0, 1, 0, 0, -1, -1, 0, 0, 1, 0, 1, -1, 0}; //encoder lookup table
volatile unsigned long last_interrupt_time = 0;
volatile unsigned long interrupt_time = 0;

//menu vars
const byte none = 0;
const byte menu = 1;
const byte doSunrise = 11;
const byte setBright = 12;
const byte sunFollow = 13;
const byte sunHour = 14;
const byte sunMinute = 15;
const byte setClk = 20;
const byte cHour = 21;
const byte cMinute = 22;
const byte cSecond = 23;
const byte cDay = 24;
const byte cMonth = 25;
const byte cYear = 26;
volatile int EEPROMVar;
volatile boolean inMenu = 0;
volatile int timeVar;
volatile byte knobVar = 0;
volatile byte selectIndex = 0;
char* selectText [] = { "Rise ? ", "Rise HR?", "RiseMin", "SetLux?", "Follow?", "Set Clk" };
char* selectClock [] = { "Set Hr", "Set Min", "Set Sec", "Set Day", "Set Mth", "Set Year" };

void setup(void) {

  if (debugbit) {
    Serial.begin(115200);
    while (!Serial);
    Serial.println("Start!");

    EEPROM.update( BrightStor, 234 );
    EEPROM.update( MaxHour, 8 );
    EEPROM.update( MaxMinute, 30 );
    EEPROM.update( EESunFollow, 1 );
    EEPROM.update( SunOn, 1 );

    alarmHour = 8;
    alarmMinute = 30;
  }

  pinMode(pinCS1, OUTPUT);
  pinMode(pinWR, OUTPUT);
  pinMode(pinDATA, OUTPUT);

  HT1632.begin(pinCS1, pinWR, pinDATA);
  HT1632.clear();
  HT1632.render();
  HT1632.setBrightness(1);
  toggleBlink(false);

  pinMode(stopPin, OUTPUT);
  attachInterrupt(digitalPinToInterrupt(stopPin), stop, FALLING);
  pinMode(pulsePin, OUTPUT);
  pinMode(pulsePin2, OUTPUT);

  RTC.squareWave(SQWAVE_1_HZ);
  //RTC.squareWave(SQWAVE_NONE);

  setTime(RTC.get());

  pinMode(SQWPin, INPUT_PULLUP);

  // SET 16 bit PWM
  DDRB |= (1 << 6) | (1 << 5);
  ICR1 = 0xFFFF;
  TCCR1A = 0b10101010;
  TCCR1B = 0b00011001;

  brightLevel = ( EEPROM.read( BrightStor ) * 256 + 96 );
  //brightLevel = 0;

  // Set brightness
  setBrightness(brightLevel);

  ShowClock();

  latestHour = EEPROM.read( MaxHour );
  latestMin = EEPROM.read( MaxMinute );

  if ( EEPROM.read( EESunFollow ) == 0 ) { // not following the actual sunrise
    alarmHour = latestHour;
    alarmMinute = latestMin;
  }
  else {
    getSunrise();
  }

  RTC.setAlarm(ALM2_MATCH_HOURS, 0, alarmMinute, alarmHour, 1); //Alarm for sunrise
  RTC.alarm(ALARM_2);
  RTC.alarmInterrupt(ALARM_2, false);

  CheckDST();

  attachInterrupt(digitalPinToInterrupt(SQWPin), timeUpdate, FALLING);

  //rotary encoder
  pinMode(ENC_A, INPUT);
  digitalWrite(ENC_A, HIGH);
  pinMode(ENC_B, INPUT);
  digitalWrite(ENC_B, HIGH);

  if (!(debugbit)) {
    //encoder switch interrupt
    attachInterrupt( digitalPinToInterrupt( switchPin ), knobPress, FALLING );
    pinMode(switchPin, INPUT_PULLUP);
  }

  //add interrups for rotary gray code, pins 14 & 16
  PCICR |= (1 << PCIE0);
  PCMSK0 |= (1 << PCINT3) | (1 << PCINT2);

  sei();

}

void loop(void) {

  if ( alarmed )
  {
    alarmed = false;

    if ( minute() % 5 == 0 && second() == 0 )
    {
      setTime(RTC.get());
    }

    if ( RTC.alarm(ALARM_2) )
    {
      tripped = false;
      gotSunrise = false;

      if ( EEPROM.read( SunOn ) == 1 ) {

        alarmStart = now();

        //DO SUNRISE
        toggleLamp(1);

        static unsigned int z;

        for (z = 1; z <= steps; z++)
        {
          if ( alarmed == true && minute() % 5 == 0 && second() == 0 )
          {
            setTime(RTC.get());
            alarmed = false;
          }

          if (z < 82)
          {
            duty = (long) (((z * 100.0 / 1024.0) / 902.3) * 65535.0);
          }
          else
          {
            duty = (long) (pow(((z * 100.0 / 1024.0 + 16.0) / 116.0), 3.0) * 65535.0);
          }

          brightLevel = duty;
          setBrightness(brightLevel);

          targetMillis = ( (unsigned long) ( millis() + interval ) );

          do {} while ( targetMillis > millis() );

          if (tripped == true)
          {
            break;
          }
        }
      }
    }
  }

  if ( ( now() - alarmStart > 9000 ) && ( readBright() > ( EEPROM.read( BrightStor ) * 256 + 96 ) ) ) //Dim after two hours @ full brightness [OVER 9000 SECONDS!]
  {
    brightLevel = ( EEPROM.read( BrightStor ) * 256 + 96 );
    setBrightness(brightLevel);
  }

  if ( ( hour() > 0 || hour () < 4 ) && ( month() == 3 || month() == 11 ) && minute() == 0 && second() == 0 ) {
    CheckDST();
  }

  if ( hour() > 12 && gotSunrise == false ) {
    getSunrise();
  }

}

ISR(PCINT0_vect)
{

  old_AB <<= 2; //remember previous state
  old_AB |= ( ENC_RD >> 2 & 0x03 );
  encVal += (enc_states[( old_AB & 0x0f )]);

  /* post "Navigation forward/reverse" event */
  if ( encVal > 3 || encVal < -3 ) {
    if ( inMenu == 0  ) {
      //Serial.println("Not In Menu");
      encVal = 0;
      return;
    }
    if ( knobVar == menu || knobVar == setClk ) { //on main menu
      selectIndex = ( selectIndex + constrain( encVal, -1, 1 ) ) % 6;
      if ( selectIndex > 5 ) {
        selectIndex = 5;
      }
      encVal = 0;
    }
    else {
      encVal = constrain( encVal, -1, 1 );
      KnobUpdate();
      encVal = 0;
    }
  }
}

void stop() {
  static unsigned long stop_last_interrupt_time = 0;
  unsigned long stop_interrupt_time = millis();

  // If interrupts come faster than 250ms, assume it's a bounce and ignore
  if (stop_interrupt_time - stop_last_interrupt_time > 250)
  {
    if ( inMenu ) {
      if ( knobVar == cYear || knobVar == cMonth || knobVar == cDay || knobVar == cSecond || knobVar == cMinute || knobVar == cHour ) {
        knobVar = setClk;
      }
      else if ( knobVar == doSunrise || knobVar == setBright || knobVar == sunFollow || knobVar == sunHour || knobVar == sunMinute || knobVar == setClk) {
        if ( knobVar == setClk ) {
          selectIndex = 5;
        }
        knobVar = menu;
      }
      else {
        knobVar = none;
        inMenu = 0;
        HT1632.clear();
        HT1632.render();
      }
    }
    else {
      if ( readBright() == ( EEPROM.read( BrightStor ) * 256 + 96 ) ) //if complete or has been tripped previously
      {
        toggleLamp(0);
        HT1632.clear();
        HT1632.render();
      }
      else if ( readBright() == 0 ) //if lamp is off
      {
        toggleLamp(1);
        ShowClock();
      }
      else //in sunrise period
      {
        tripped = true;
        brightLevel = ( EEPROM.read( BrightStor ) * 256 + 96 );
        setBrightness( brightLevel );
      }
    }
  }
  stop_last_interrupt_time = stop_interrupt_time;
}

void toggleLamp(boolean on) {
  if ( on == 1 ) {
    brightLevel = ( EEPROM.read( BrightStor ) * 256 + 96 );
    setBrightness(brightLevel);
  }
  else {
    brightLevel = 0;
    setBrightness(brightLevel);
  }
}

void timeUpdate() {
  if ( readBright() > 0 ) //Only show clock when lamp on
  {
    ShowClock();
  }
  alarmed = true;
}

void ShowClock() {
  byte Ta = (hour() / 10);
  byte Tb = (hour() % 10);
  byte Tc = (minute() / 10);
  byte Td = (minute() % 10);
  byte Te = (second() / 10);
  byte Tf = (second() % 10);
  char num[11] = {'0', '1', '2', '3', '4', '5', '6', '7', '8', '9'};
  char Th[1] = {num[Ta]};
  char Th2[1] = {num[Tb]};
  char Tm[1] = {num[Tc]};
  char Tm2[1] = {num[Td]};
  char Ts[1] = {num[Te]};
  char Ts2[1] = {num[Tf]};
  char showhour[9] = {Th[0], Th2[0], ':', Tm[0], Tm2[0], ':', Ts[0], Ts2[0]};
  HT1632.drawText(showhour, 0, 0, FONT_7X5, FONT_7X5_END, FONT_7X5_HEIGHT);
  HT1632.render();
}

bool IsDST() {
  //January, february, and december are out.
  if (month() < 3 || month() > 11) {
    return false;
  }
  //April to October are in
  if (month() > 3 && month() < 11) {
    return true;
  }
  //march
  if (month() == 3)
  {
    if (day() > 14) {
      return true;
    }
    //before second sunday is out
    if (day() - weekday() < 7) {
      return false;
    }
    //before 2am on second sunday is out
    if (weekday() == 1 && hour() < 2) {
      return false;
    }
    //otherwise in
    {
      return true;
    }
  }
  else //november
  {
    //before first sunday is in
    if (day() - weekday() < 0) {
      return true;
    }
    //after first sunday is out
    if (day() - weekday() > 7) {
      return false;
    }
    //before 2am on second sunday
    if (weekday() == 1 && hour() < 2 && day() - weekday() < 7) {
      return true;
    }
    //otherwise out
    {
      return false;
    }
  }
}

void CheckDST() {
  if ( EEPROM.read(DST) == 0 && IsDST() == 1 )
  {
    EEPROM.write(DST, 1);
    detachInterrupt(digitalPinToInterrupt(SQWPin));
    setTime(RTC.get());
    setTime( hour() + 1, minute(), second(), day(), month(), year() );
    RTC.set( now() );
    attachInterrupt(digitalPinToInterrupt(SQWPin), timeUpdate, FALLING);
  }

  if ( EEPROM.read(DST) == 1 && IsDST() == 0 )
  {
    EEPROM.write(DST, 2);
    detachInterrupt(digitalPinToInterrupt(SQWPin));
    setTime(RTC.get());
    setTime( hour() - 1, minute(), second(), day(), month(), year() );
    RTC.set(now());
    attachInterrupt(digitalPinToInterrupt(SQWPin), timeUpdate, FALLING);
  }

  if ( EEPROM.read(DST) == 2 && day() > 8 )
  {
    EEPROM.write(DST, 0);
  }
}

void setBrightness(unsigned int set) {
  OCR1A = set;
  OCR1B = set;
}

unsigned int readBright() {
  return OCR1A;
}

void getSunrise() {

  latestHour = EEPROM.read( MaxHour );
  latestMin = EEPROM.read( MaxMinute );

  if ( EEPROM.read( EESunFollow ) == 0 ) { // not following the actual sunrise
    alarmHour = latestHour;
    alarmMinute = latestMin;
  } else {
    TimeLord Sun;
    Sun.TimeZone( ( -8 + IsDST() ) * 60  );
    Sun.Position( latitude, longitude );
    time_t next = ( now() + ( ( 36.0 - hour() ) * 60 * 60 ) ); //noon tomorrow
    byte tmo[] = { 0, 0, 12, (byte) day(next), (byte) month(next), 0 };
    Sun.SunRise(tmo);
    //Serial.print("Sunrise: ");
    //Serial.print((int) tmo[tl_hour]);
    //Serial.print(":");
    //Serial.println((int) tmo[tl_minute]);

    if ( (int) tmo[tl_hour] < latestHour ) {
      alarmHour = (int) tmo[tl_hour];
      alarmMinute = (int) tmo[tl_minute];
    }

    if ( (int) tmo[tl_hour] == latestHour ) {
      alarmHour = (int) tmo[tl_hour];

      if ( (int) tmo[tl_minute] <= latestMin ) {
        alarmMinute = (int) tmo[tl_minute];
      }
      else {
        alarmMinute = latestMin;
      }
    }

    if ( (int) tmo[tl_hour] > latestHour ) {
      alarmHour = latestHour;
      alarmMinute = latestMin;
    }

  }

  RTC.setAlarm(ALM2_MATCH_HOURS, 0, alarmMinute, alarmHour, 1); //Alarm for sunrise
  RTC.alarm(ALARM_2);
  RTC.alarmInterrupt(ALARM_2, false);

  gotSunrise = true;

}

void toggleBlink(boolean blinky) {
  if (blinky) {
    HT1632.sendCommand(HT1632_CMD_BLON);
  }
  else {
    HT1632.sendCommand(HT1632_CMD_BLOFF);
  }
}

void ClockMenu(String text) {
  char charBuf[10];
  text.toCharArray(charBuf, 10);
  HT1632.clear();
  HT1632.drawText(charBuf, 0, 1, FONT_5X4, FONT_5X4_END, FONT_5X4_HEIGHT, 1);
  HT1632.render();
}

void knobPress() {
  // Yes, press it precious
  interrupt_time = millis();

  // If interrupts come faster than 250ms, assume it's a bounce and ignore
  if (interrupt_time - last_interrupt_time > 250)
  {
    if ( inMenu == 0  ) {
      inMenu = 1;
      KnobSelect();
    }

    //in clock menu
    if ( knobVar == setClk )
    {
      switch ( selectIndex ) {
        case 0:
          knobVar = cHour;
          break;
        case 1:
          knobVar = cMinute;
          break;
        case 2:
          knobVar = cSecond;
          break;
        case 3:
          knobVar = cDay;
          break;
        case 4:
          knobVar = cMonth;
          break;
        case 5:
          knobVar = cYear;
          break;
        default:
          break;
      }
    }
    //in main menu
    if ( knobVar == menu )
    {
      switch ( selectIndex ) {
        case 0:
          knobVar = doSunrise;
          break;
        case 1:
          knobVar = sunHour;
          break;
        case 2:
          knobVar = sunMinute;
          break;
        case 3:
          knobVar = setBright;
          break;
        case 4:
          knobVar = sunFollow;
          break;
        case 5:
          selectIndex = 0;
          knobVar = setClk;
          break;
        default:
          break;
      }
    }
    last_interrupt_time = interrupt_time;
  }
}

void KnobSelect() {

  last_interrupt_time = interrupt_time;

  sei();
  detachInterrupt(digitalPinToInterrupt(SQWPin)); // disable clock update
  toggleBlink(true);

  setTime(RTC.get());

  knobVar = menu;
  do {
    String outputVar = "test";
    if ( knobVar == menu ) {
      ClockMenu(selectText[selectIndex]);
    }
    if ( knobVar == setClk ) {
      ClockMenu(selectClock[selectIndex]);
    }
    if ( knobVar == doSunrise ) {
      EEPROMVar = EEPROM.read( SunOn );
      if ( EEPROMVar == 0 ) {
        ClockMenu( "Rise? N" );
      }
      else {
        ClockMenu( "Rise? Y" );
      }
    }
    if ( knobVar == setBright ) {
      EEPROMVar = EEPROM.read( BrightStor );
      outputVar = "Lux: ";
      outputVar = outputVar + String(EEPROMVar);
      ClockMenu( outputVar );
    }
    if ( knobVar == sunFollow ) {
      EEPROMVar = EEPROM.read( EESunFollow );
      if ( EEPROMVar == 0 ) {
        ClockMenu( "No Foll" );
      }
      else {
        ClockMenu( "Yes Foll" );
      }
    }
    if ( knobVar == sunHour ) {
      EEPROMVar = EEPROM.read( MaxHour );
      outputVar = "Hour: ";
      outputVar = outputVar + String(EEPROMVar);
      ClockMenu( outputVar );
    }
    if ( knobVar == sunMinute ) {
      EEPROMVar = EEPROM.read( MaxMinute );
      outputVar = "Min: ";
      outputVar = outputVar + String(EEPROMVar);
      ClockMenu( outputVar );
    }
    if ( knobVar == cHour ) {
      timeVar = hour();
      outputVar = "Hour: " ;
      outputVar = outputVar + String(timeVar);
      ClockMenu( outputVar );
    }
    if ( knobVar == cMinute ) {
      timeVar = minute();
      outputVar = "Min: ";
      outputVar = outputVar + String(timeVar);
      ClockMenu( outputVar );
    }
    if ( knobVar == cSecond ) {
      timeVar = second();
      outputVar = "Sec: ";
      outputVar = outputVar + String(timeVar);
      ClockMenu( outputVar );
    }
    if ( knobVar == cDay ) {
      timeVar = day();
      outputVar = "Day: ";
      outputVar = outputVar + String(timeVar);
      ClockMenu( outputVar );
    }
    if ( knobVar == cMonth ) {
      timeVar = month();
      outputVar = "Mth: ";
      outputVar = outputVar + String(timeVar);
      ClockMenu( outputVar );
    }
    if ( knobVar == cYear ) {
      timeVar = year();
      outputVar = "Yr: ";
      outputVar = outputVar + String(timeVar);
      ClockMenu( outputVar );
    }
  } while ( inMenu );

  knobVar = 0;
  selectIndex = 0;

  HT1632.clear();
  HT1632.render();
  NOP();
  toggleBlink(false);

  getSunrise();

  RTC.set( now() );

  HT1632.clear();
  HT1632.render();
  NOP();

  attachInterrupt(digitalPinToInterrupt(SQWPin), timeUpdate, FALLING);
}

void KnobUpdate() {
  // To adjust RTC clock time/date
  // setTime(HH, MM, SS, DD, M, YYYY);
  if ( knobVar == cHour ) {
    setTime( now() + (long) encVal * 60.0 * 60.0);
  }

  if ( knobVar == cMinute ) {
    setTime( hour(), minute() + encVal, second(), day(), month(), year() );
  }

  if ( knobVar == cSecond ) {
    setTime( now() + encVal );
  }

  if ( knobVar == cDay ) {
    setTime( now() + (long) encVal * 24.0 * 60.0 * 60.0 );
  }

  if ( knobVar == cMonth ) {
    byte setVal;
    if ( month () + encVal < 1 ) {
      setVal = 12;
    }
    else if ( month () + encVal > 12 ) {
      setVal = 1;
    }
    else {
      setVal = month() + encVal;
    }
    setTime(hour(), minute(), second(), day(), setVal, year());
  }

  if ( knobVar == cYear ) {
    setTime(hour(), minute(), second(), day(), month(), year() + encVal);
  }

  // Set sunrise latest hour (eeprom)
  if ( knobVar == sunHour ) {
    alarmHour = ( EEPROM.read( MaxHour ) + encVal ) % 24;
    if ( alarmHour > 23 ) {
      alarmHour = 23;
    }
    EEPROM.write( MaxHour, alarmHour );
  }

  // Set sunrise latest minute (eeprom)
  if ( knobVar == sunMinute ) {
    alarmMinute = ( EEPROM.read( MaxMinute ) + ( encVal * 5 ) ) % 60;
    if ( alarmMinute > 55 ) {
      alarmMinute = 55;
    }
    alarmMinute = round(alarmMinute / 5) * 5; //Constrain to 5 minute intervals
    EEPROM.write( MaxMinute, alarmMinute );
  }

  // Set sunrise follow or not (eeprom)

  if ( knobVar == sunFollow ) {
    EEPROMVar = EEPROM.read( EESunFollow );

    if ( EEPROMVar == 0 ) {
      EEPROM.write( EESunFollow, 1 );
    }
    else {
      EEPROM.write( EESunFollow, 0 );
    }
  }

  // Set sunrise on or off (eeprom)
  if ( knobVar == doSunrise ) {
    EEPROMVar = EEPROM.read( SunOn );

    if ( EEPROMVar == 0 ) {
      EEPROM.write( SunOn, 1 );
    }
    else {
      EEPROM.write( SunOn, 0 );
    }
  }

  // Adjust light brightLevel (eeprom)
  if ( knobVar == setBright ) {
    EEPROMVar = EEPROM.read( BrightStor );

    if ( EEPROMVar + ( encVal ) < 255 ) {
      brightLevel = ( EEPROMVar + ( encVal ) ) * 256 + 96;
      EEPROM.write( BrightStor, EEPROMVar + ( encVal ) );
    }
    else {
      brightLevel = 65535;
      EEPROM.write( BrightStor, 255 );
    }

    setBrightness(brightLevel);

  }
}

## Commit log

2016-08-16 Adding eagle files etc
    [SunriseClockSplit.brd, SunriseClockSplit.sch]
2016-08-16 Fix screen not clearing when using menu with lamp off
    [SunriseClock.ino]
2016-08-17 Changes, eagle is borked
    [SunriseClockSplit.brd, SunriseClockSplit.sch]
2016-08-17 Revert "Changes, eagle is borked"
    This reverts commit ce4402d5bc8679ed222257ac0a5ccbb3afe4734b.
    [SunriseClockSplit.brd, SunriseClockSplit.sch]
2016-08-22 Changes
    - swap MOSFET for PNP
    - constrain alarm minute to 5 minute intervals
    [SunriseClock.ino]
2016-08-22 Updated Schematics
2016-08-23 Updated schematic
2016-08-27 Adding drawings
    [SunriseClockSwitchesv2.brd, SunriseClockSwitchesv2.sch]
2016-08-27 Readme updates, adding pricing doc
    [Pricing.xlsx]
2016-10-02 Updated schematic + code
    Added DC-DC converter to limit power draw from arduino, modified
    switching circuit to have first FET driven by arduino switch the second
    FET with 12V to ensure full turn on and current drain. 5V just wasn't
    quite cutting it with these. Added auto-increase of brightness as well.
2016-10-02 Updated eagle files and schematic
    [SunriseClockMainv3.brd, SunriseClockMainv3.sch]

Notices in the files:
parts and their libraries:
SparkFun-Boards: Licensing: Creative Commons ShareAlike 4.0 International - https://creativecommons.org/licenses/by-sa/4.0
